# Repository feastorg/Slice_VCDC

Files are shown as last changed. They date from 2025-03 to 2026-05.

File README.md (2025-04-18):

# Current & Voltage Reader Slice

Current and voltage reader slice for AC and DC supplies.

## Introduction

[Short introduction on the project.]

## Usage

[Explain how to use the project. Include examples and screenshots if applicable.]

## Documentation

Please refer to the [docs](/docs) for more info.

---

<div align="center">
  <p>
    
    
  </p>
</div>

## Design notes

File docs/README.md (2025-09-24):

# Notes

## references

-

## parts dump

- PCB TERMINAL BLOCK - LPTA 16/ 2- (1000V, 76A)
  - https://www.digikey.ca/en/products/detail/phoenix-contact/1333817/18175936
- ADUM5010ARSZ isolated dc dc supply
  - https://www.digikey.ca/en/products/detail/analog-devices-inc/ADUM5010ARSZ-RL7/3821210
- 10uF bulk cap: CAP CER 10UF 6.3V X5R 0603
  - https://www.digikey.ca/en/products/detail/tdk-corporation/C1608X5R0J106K080AB/2732927
- 0.1uF HF bypass on iso: CAP CER 0.1UF 50V X5R 0603
  - https://www.digikey.ca/en/products/detail/tdk-corporation/C1608X5R1H104K080AA/2732891
- 10nF EMI filter cap on iso: CAP CER 10000PF 25V C0G 0603
  - https://www.digikey.ca/en/products/detail/kemet/C0603C103J3GECAUTO/6575890
- AMC1311 2-V input, precision voltage sensing reinforced isolated amplifier
  - https://www.digikey.ca/en/products/detail/texas-instruments/AMC1311BDWVR/8020495
  - https://www.ti.com/product/AMC1311
- ACS724LLCTR-50AB-T SENSOR CURRENT HALL IC
  - https://www.digikey.ca/en/products/detail/allegro-microsystems/ACS724LLCTR-50AB-T/5400758
  - https://www.allegromicro.com/en/Products/Sense/Current-Sensor-ICs/Zero-To-Fifty-Amp-Integrated-Conductor-Sensor-ICs/ACS724-5

### other

- ACS37800 - Isolated, Programmable AC and DC Power Monitoring IC with I2C or SPI Interface
  - ACS37800KMACTR-030B3-I2C: https://www.digikey.ca/en/products/detail/allegro-microsystems/ACS37800KMACTR-030B3-I2C/13563666
  - https://www.sparkfun.com/sparkx-power-meter-acs37800-qwiic.html
- Press Fit Terminals
  - [Phoenix Contact TDPT 4/2-SP-635 ZB (Phoenix Contact)](https://www.phoenixcontact.com/en-us/products/printed-circuit-board-terminal-tdpt-4-2-sp-635-zb-1017521)

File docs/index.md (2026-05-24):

---
title: "Slice VCDC Documentation"
description: "Overview and entry page for Slice VCDC project documentation."
nav_exclude: true
---

Welcome to the Slice VCDC project documentation.

## Board Renders

<figure style="display:inline-block; text-align:center; margin:10px;">
  Board Top
  <figcaption>Top</figcaption>
</figure>

<figure style="display:inline-block; text-align:center; margin:10px;">
  Board Bottom
  <figcaption>Bottom</figcaption>
</figure>

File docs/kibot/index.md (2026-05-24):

---
title: "KiBot Outputs"
description: "Index for KiBot-generated PCB artifacts."
layout: "page"
---

These are the docs & KiBot Outputs for Slice VCDC

The following files were generated from the latest PCB build:

- [Schematic.pdf](./Schematic.pdf)
- [PCB.pdf](./PCB.pdf)
- [kibot.log](./kibot.log)
- [BREAD_Slice-bom.html](./BREAD_Slice-bom.html)
- [BREAD_Slice-ibom.html](./BREAD_Slice-ibom.html)

_Last updated automatically by KiBot via GitHub Actions._

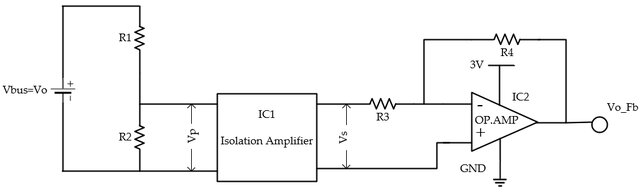
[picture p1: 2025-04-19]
docs/images/Block-diagram-of-the-proposed-isolated-DC-voltage-sensor-VS-2_W640.jpg

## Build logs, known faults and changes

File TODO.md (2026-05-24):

# TODO

## Pass 1 — CI Pipeline

- [x] Pipeline added
- [x] DRC: FAIL
- [x] ERC: PASS
- [ ] Fab: FAIL (Generate SCH files step)
- [ ] gen-kibot-index: SKIPPED
- [ ] deploy-pages: SKIPPED

## Pass 2 — Pre-Fab Review

- [ ] Investigate and fix DRC errors
- [ ] Investigate Fab "Generate SCH files" failure
- [ ] Verify BOM completeness and sourcing
- [ ] Confirm board outline and mounting holes
- [ ] Footprint verification against datasheets
- [ ] Design review sign-off

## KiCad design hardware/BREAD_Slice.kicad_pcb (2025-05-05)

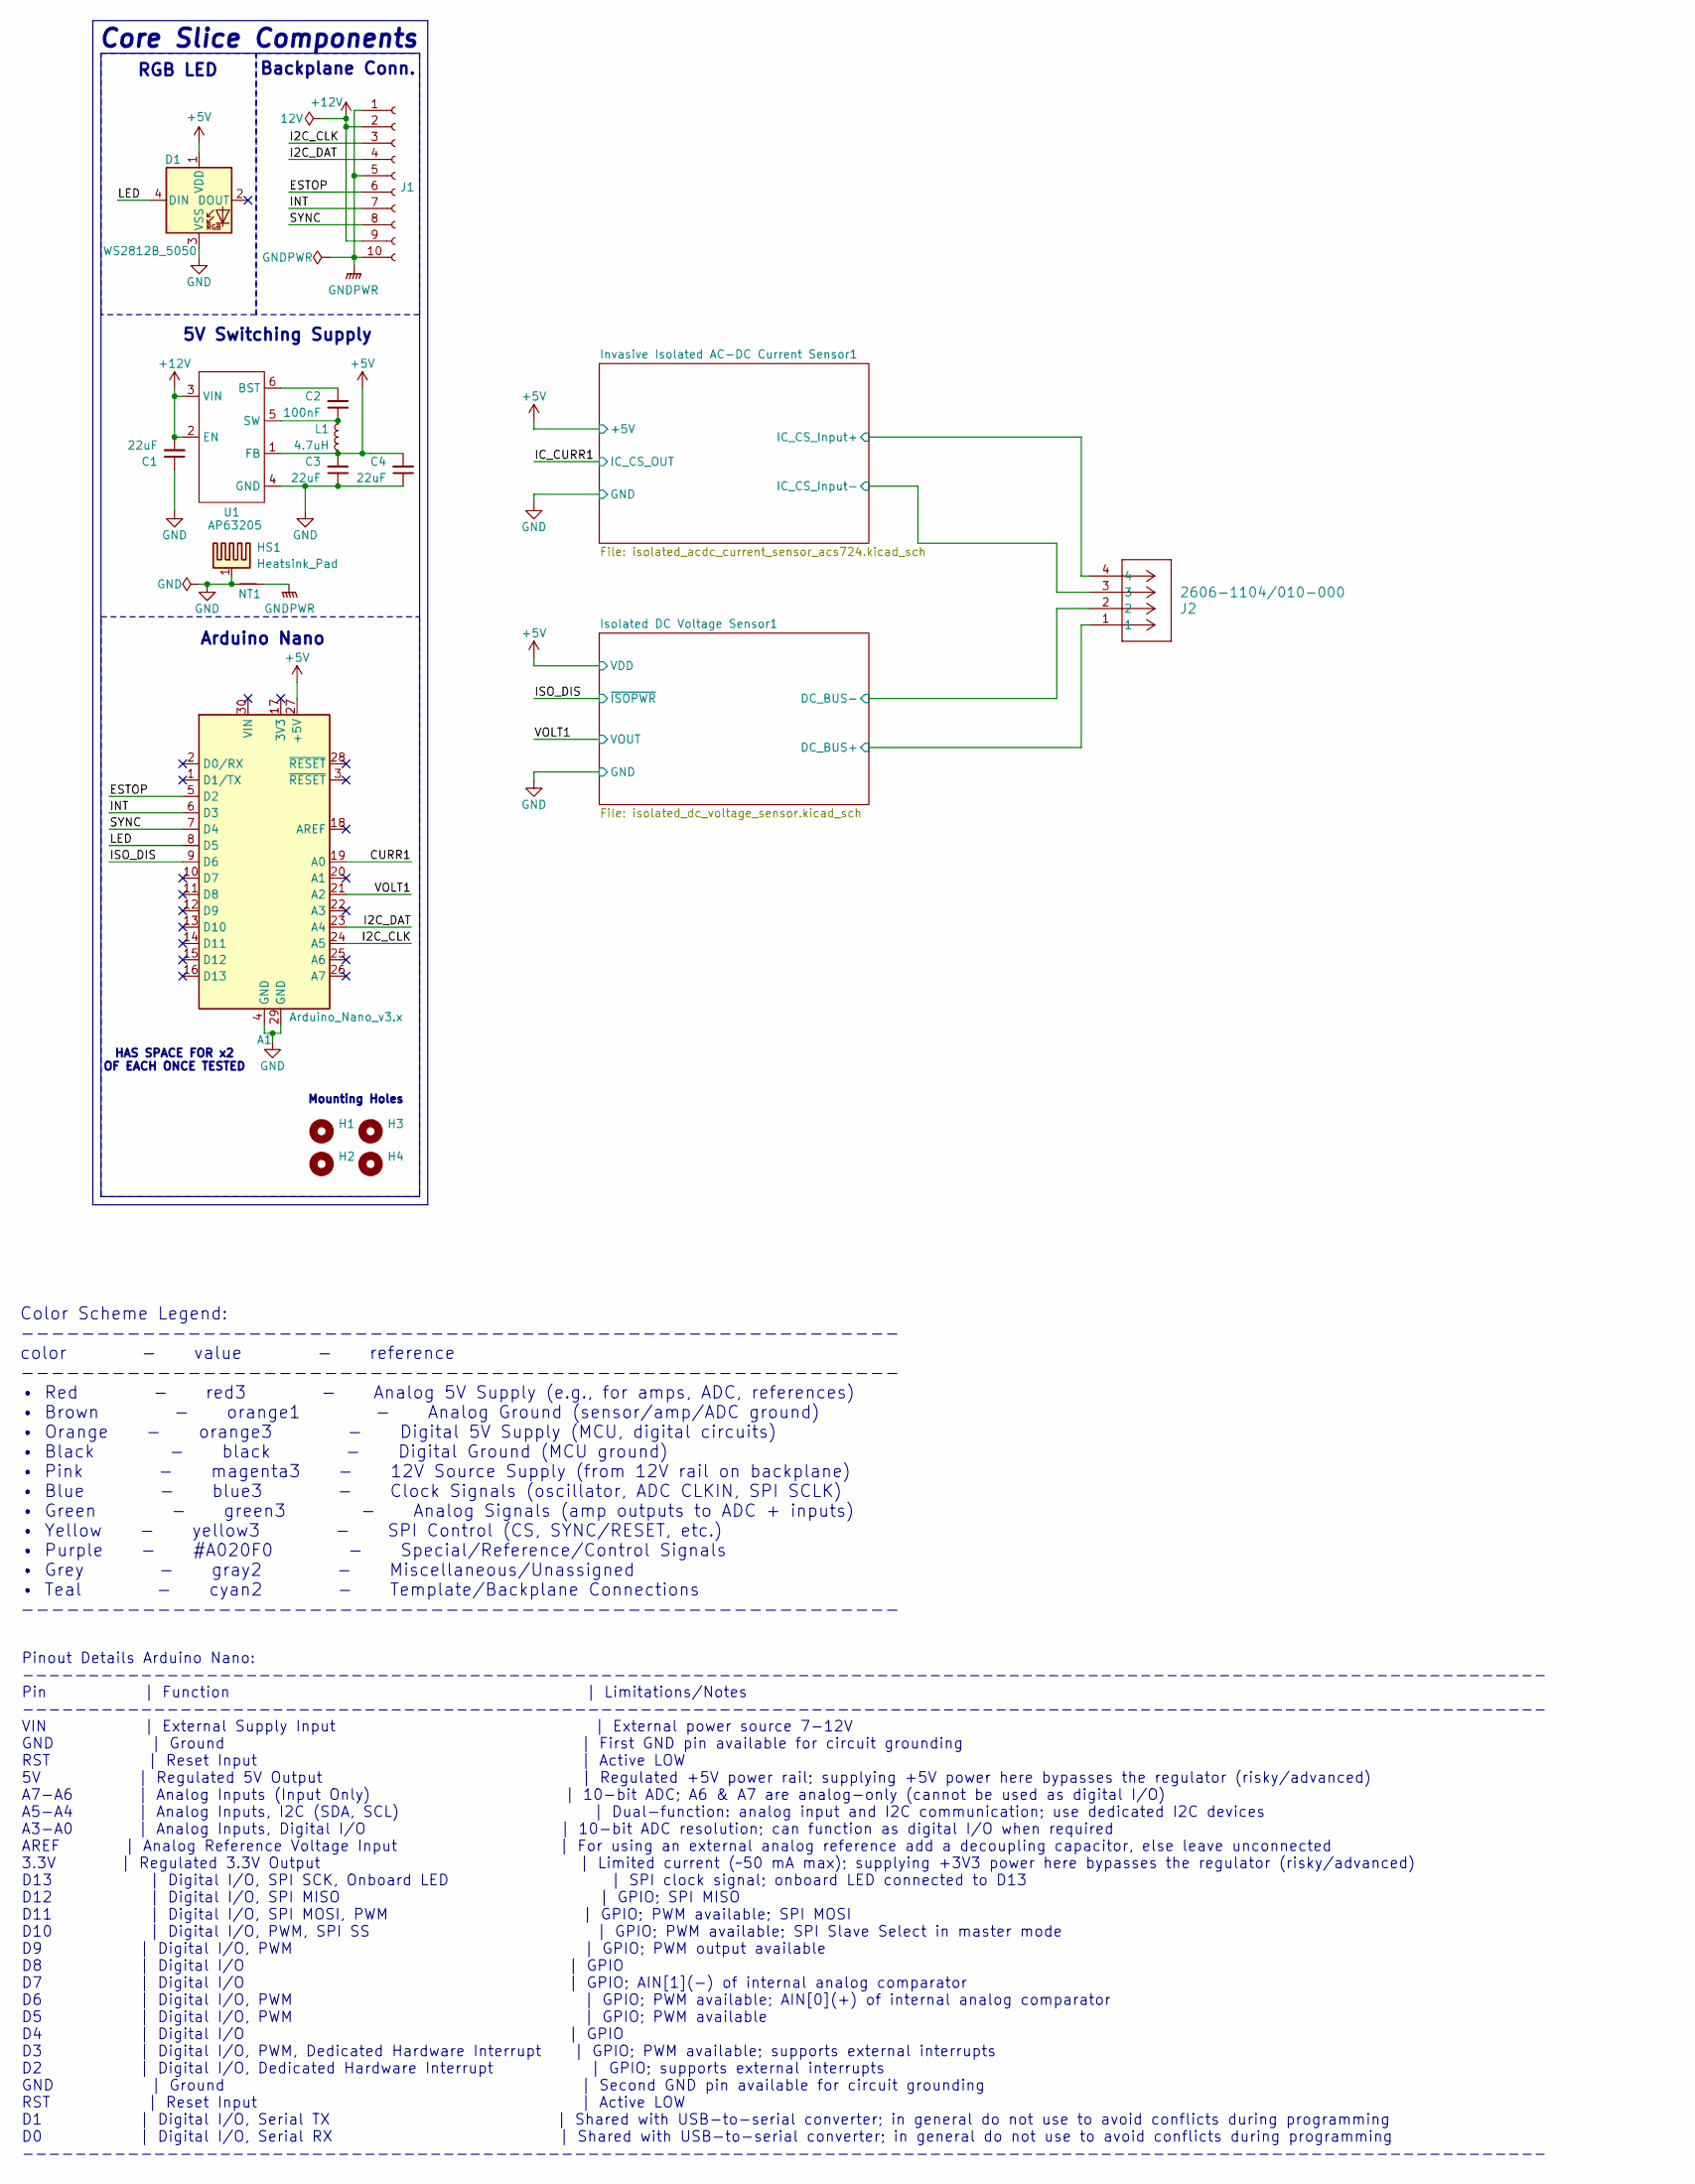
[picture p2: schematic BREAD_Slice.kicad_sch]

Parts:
A1: Arduino_Nano_v3.x; Arduino_Nano
C1, C3, C4: 22uF; C_1206_3216Metric
C2: 100nF; C_1206_3216Metric
D1: WS2812B_5050; WS2812-5050-4PIN
H1, H2, H3, H4: MountingHole; MountingHole_5mm
HS1: Heatsink_Pad; Thermal Pad
J1: Conn_01x10_Female; PinSocket_1x10_P2.54mm_Horizontal
J2: 2606-1104/010-000; CONN4_2606-1104&slash_010-000_WAG
L1: 4.7uH; L_1210_3225Metric
NT1: NetTie_2; NetTie-2_SMD_Pad2.0mm
U1: AP63205; TSOT-23-6

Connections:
+5V: A1.27 (+5V), C3.2, C4.2, D1.1 (VDD), L1.2, U1.1 (FB); also elsewhere on the board
+12V: C1.2, J1.2, J1.9, U1.2 (EN), U1.3 (VIN)
/CURR1: A1.19 (A0)
/ESTOP: A1.5 (D2), J1.6
/I2C_CLK: A1.24 (A5), J1.3
/I2C_DAT: A1.23 (A4), J1.4
/INT: A1.6 (D3), J1.7
/ISO_DIS: A1.9 (D6); also elsewhere on the board
/Invasive Isolated AC-DC Current Sensor1/IC_CS_Input+: J2.4; also elsewhere on the board
/Invasive Isolated AC-DC Current Sensor1/IC_CS_Input-: J2.3; also elsewhere on the board
/Isolated DC Voltage Sensor1/DC_BUS+: J2.1; also elsewhere on the board
/Isolated DC Voltage Sensor1/DC_BUS-: J2.2; also elsewhere on the board
/LED: A1.8 (D5), D1.4 (DIN)
/SYNC: A1.7 (D4), J1.8
/VOLT1: A1.21 (A2); also elsewhere on the board
GND: A1.4 (GND), A1.29 (GND), C1.1, C3.1, C4.1, D1.3 (VSS), HS1.1, NT1.1, U1.4 (GND); also elsewhere on the board
GNDPWR: J1.1, J1.5, J1.10, NT1.2
unnamed: C2.2, U1.6 (BST)
unnamed: C2.1, L1.1, U1.5 (SW)

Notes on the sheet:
5V Switching Supply
HAS SPACE FOR x2 OF EACH ONCE TESTED
Pinout Details Arduino Nano: -------------------------------------------------------------------------------------------------------------------- Pin | Function | Limitations/Notes -------------------------------------------------------------------------------------------------------------------- V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
RGB LED
Color Scheme Legend: ---------------------------------------------------------- color - value - reference ---------------------------------------------------------- • Red - red3 - Analog 5V Supply (e.g., for amps, ADC, references) • Brown - orange1 - Analog Ground (sensor/amp/ADC ground) • Orange -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
Core Slice Components
Arduino Nano
Mounting Holes
Backplane Conn.

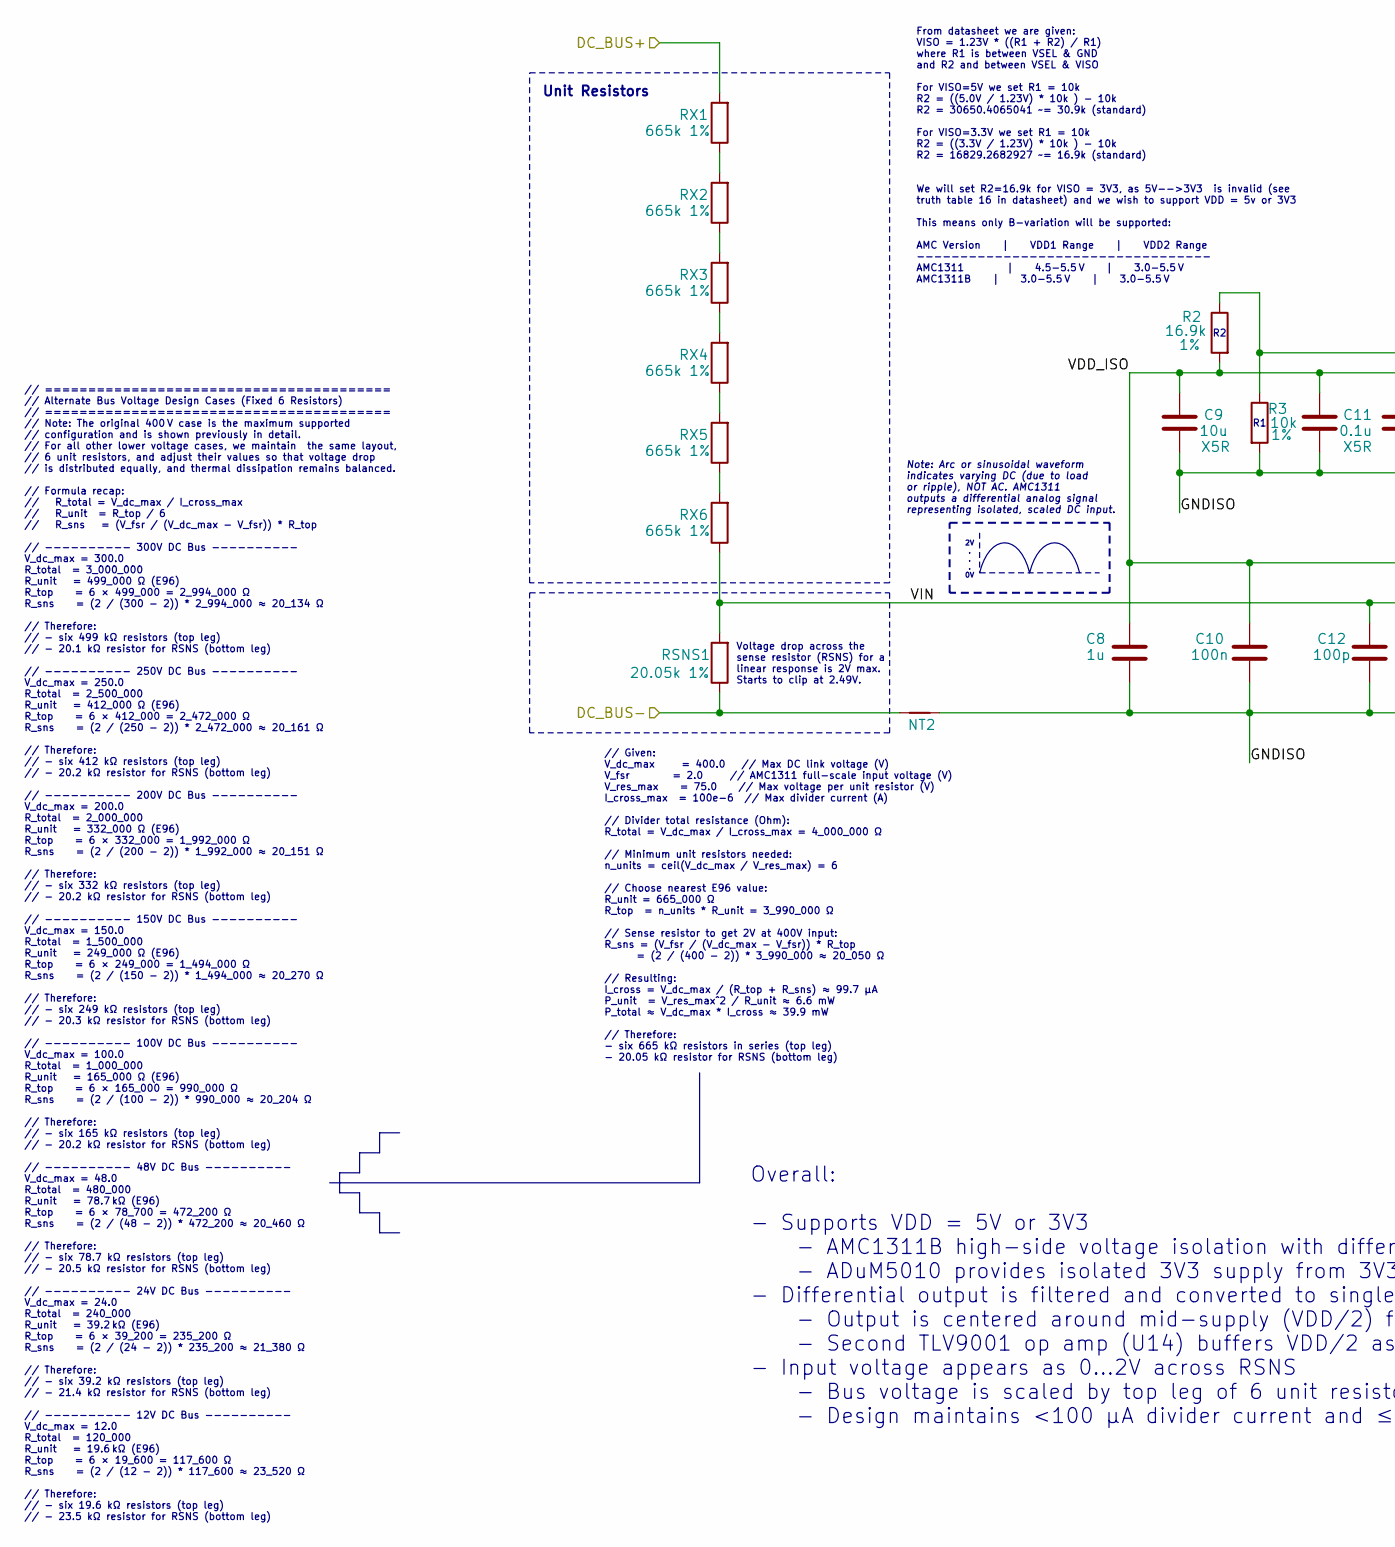
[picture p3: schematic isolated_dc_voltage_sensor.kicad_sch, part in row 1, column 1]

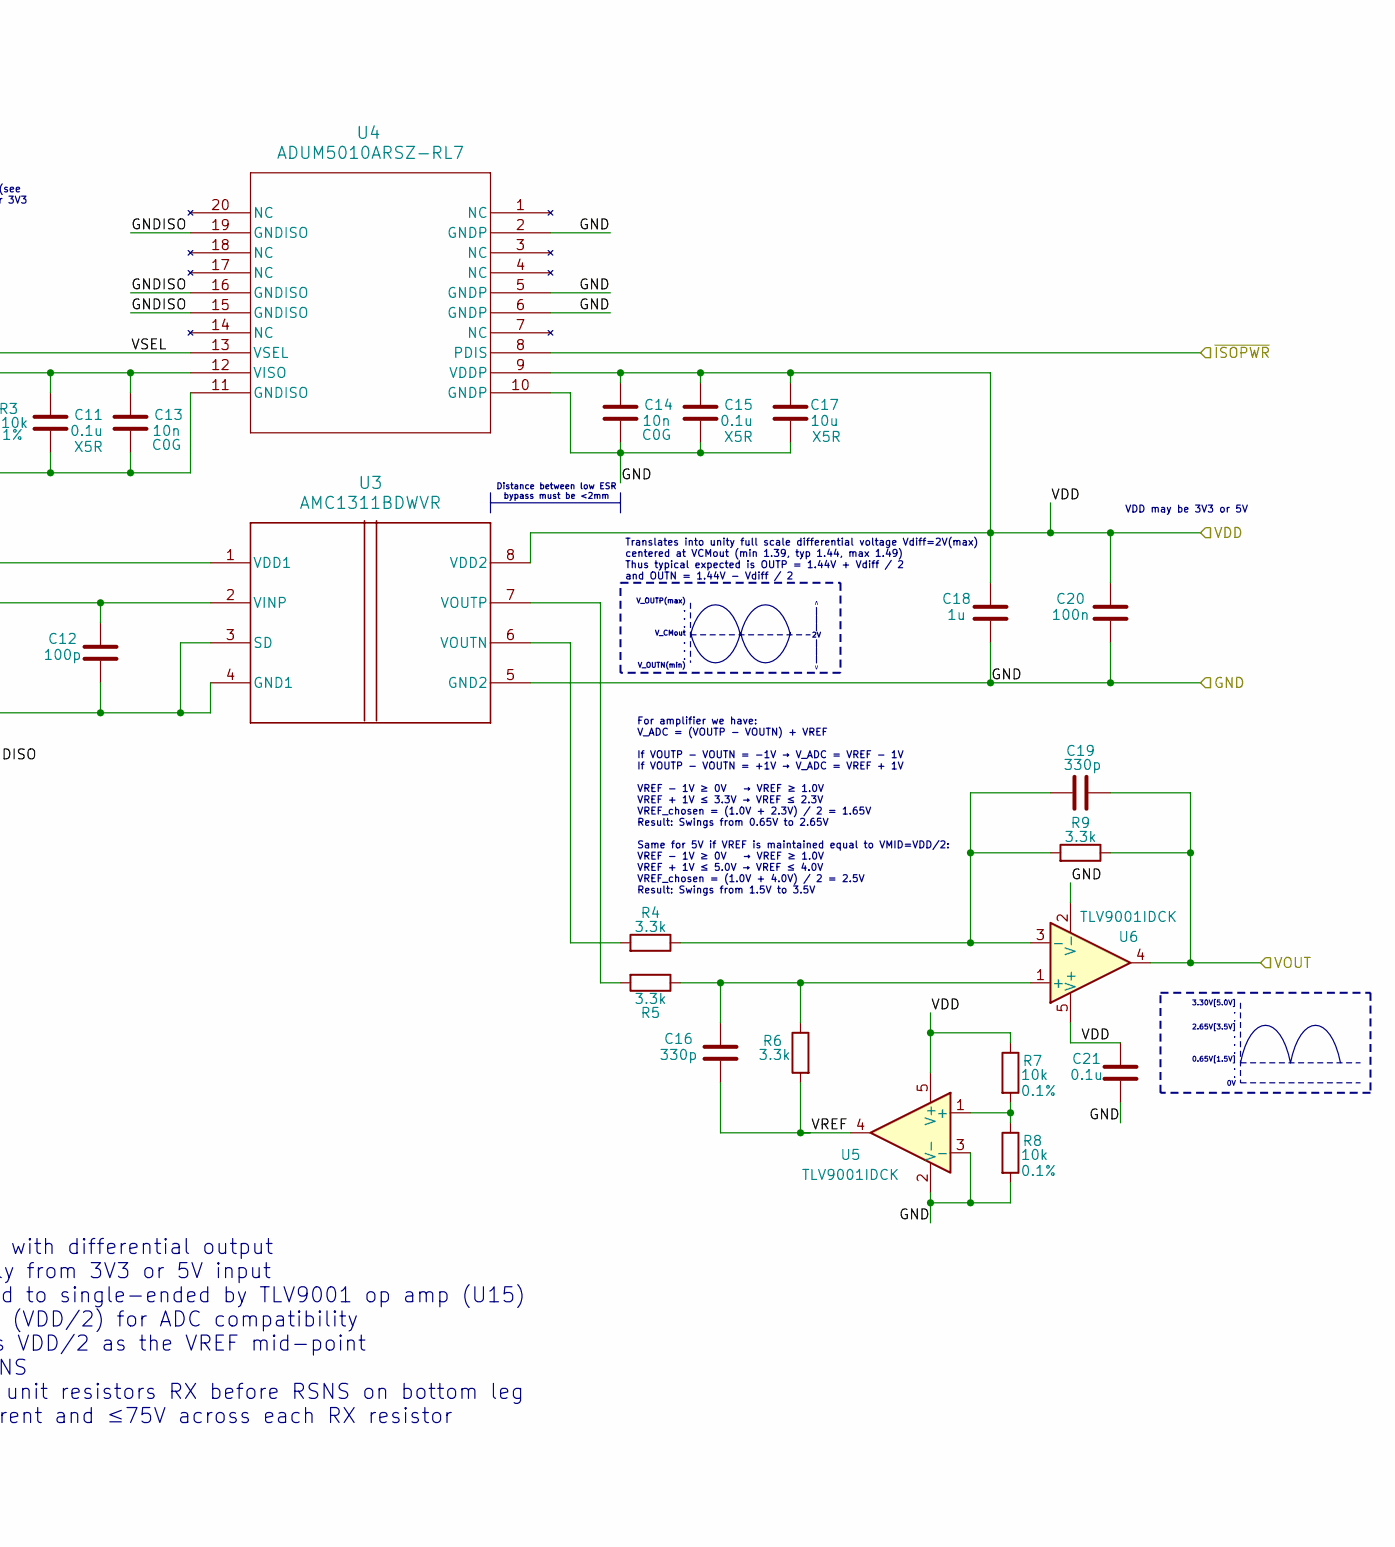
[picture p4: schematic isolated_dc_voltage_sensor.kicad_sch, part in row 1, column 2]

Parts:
C8: 1u; C_0603_1608Metric_Pad1.08x0.95mm_HandSolder
C9, C17: 10u; C_0603_1608Metric_Pad1.08x0.95mm_HandSolder
C10: 100n; C_0603_1608Metric_Pad1.08x0.95mm_HandSolder
C11, C15: 0.1u; C_0603_1608Metric_Pad1.08x0.95mm_HandSolder
C12: 100p; C_0603_1608Metric_Pad1.08x0.95mm_HandSolder
C13, C14: 10n; C_0603_1608Metric_Pad1.08x0.95mm_HandSolder
C16, C19: 330p; C_0805_2012Metric_Pad1.18x1.45mm_HandSolder
C18: 1u; C_0805_2012Metric_Pad1.18x1.45mm_HandSolder
C20: 100n; C_0805_2012Metric_Pad1.18x1.45mm_HandSolder
C21: 0.1u; C_0805_2012Metric_Pad1.18x1.45mm_HandSolder
NT2: NetTie_2; NetTie-2_SMD_Pad0.5mm
R2: 16.9k; R_0603_1608Metric_Pad0.98x0.95mm_HandSolder
R3: 10k; R_0603_1608Metric_Pad0.98x0.95mm_HandSolder
R4, R5, R6, R9: 3.3k; R_0805_2012Metric_Pad1.20x1.40mm_HandSolder
R7, R8: 10k; R_0805_2012Metric_Pad1.20x1.40mm_HandSolder
RSNS1: 20.05k 1%; R_1206_3216Metric_Pad1.30x1.75mm_HandSolder
RX1, RX2, RX3, RX4, RX5, RX6: 665k 1%; R_1206_3216Metric_Pad1.30x1.75mm_HandSolder
U3: AMC1311BDWVR; DWV0008A
U4: ADUM5010ARSZ-RL7; RS_20_ADI
U5, U6: TLV9001IDCK; SOT-353_SC-70-5

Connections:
+5V: C14.2, C15.2, C17.2, C18.2, C20.2, C21.2, R7.1, U3.8 (VDD2), U4.9 (VDDP), U5.5 (V+), U6.5 (V+); also elsewhere on the board
/ISO_DIS: U4.8 (PDIS); also elsewhere on the board
/Isolated DC Voltage Sensor1/DC_BUS+: RX1.2; also elsewhere on the board
/Isolated DC Voltage Sensor1/DC_BUS-: NT2.1, RSNS1.1; also elsewhere on the board
/Isolated DC Voltage Sensor1/GNDISO: C8.1, C9.1, C10.1, C11.1, C12.1, C13.1, NT2.2, R3.2, U3.3 (SD), U3.4 (GND1), U4.11 (GNDISO), U4.15 (GNDISO), U4.16 (GNDISO), U4.19 (GNDISO)
/Isolated DC Voltage Sensor1/VDD_ISO: C8.2, C9.2, C10.2, C11.2, C13.2, R2.2, U3.1 (VDD1), U4.12 (VISO)
/Isolated DC Voltage Sensor1/VIN: C12.2, RSNS1.2, RX6.1, U3.2 (VINP)
/Isolated DC Voltage Sensor1/VREF: C16.1, R6.2, U5.4
/Isolated DC Voltage Sensor1/VSEL: R2.1, R3.1, U4.13 (VSEL)
/VOLT1: C19.2, R9.1, U6.4; also elsewhere on the board
GND: C14.1, C15.1, C17.1, C18.1, C20.1, C21.1, R8.2, U3.5 (GND2), U4.2 (GNDP), U4.5 (GNDP), U4.6 (GNDP), U4.10 (GNDP), U5.2 (V-), U5.3 (-), U6.2 (V-); also elsewhere on the board
unnamed: RX1.1, RX2.2
unnamed: RX2.1, RX3.2
unnamed: RX3.1, RX4.2
unnamed: RX4.1, RX5.2
unnamed: RX5.1, RX6.2
unnamed: R4.2, U3.6 (VOUTN)
unnamed: R5.2, U3.7 (VOUTP)
unnamed: R7.2, R8.1, U5.1 (+)
unnamed: C16.2, R5.1, R6.1, U6.1 (+)
unnamed: C19.1, R4.1, R9.2, U6.3 (-)

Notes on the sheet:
VDD may be 3V3 or 5V
// Given: V_dc_max = 400.0 // Max DC link voltage (V) V_fsr = 2.0 // AMC1311 full-scale input voltage (V) V_res_max = 75.0 // Max voltage per unit resistor (V) I_cross_max = 100e-6 // Max divider current (A) // Divider total resistance (Ohm): R_total = V_dc_max / I_cross_max = 4_000_000 Ω // Minimu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
// ======================================== // Alternate Bus Voltage Design Cases (Fixed 6 Resistors) // ======================================== // Note: The original 400 V case is the maximum supported // configuration and is shown previously in detail. // For all other lower voltage cases, we ma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
∧ | | | 2V | | | ∨
Voltage drop across the sense resistor (RSNS) for a linear response is 2V max. Starts to clip at 2.49V.
Overall: - Supports VDD = 5V or 3V3 - AMC1311B high-side voltage isolation with differential output - ADuM5010 provides isolated 3V3 supply from 3V3 or 5V input - Differential output is filtered and converted to single-ended by TLV9001 op amp (U15) - Output is centered around mid-supply (VDD/2) for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
2V . . . 0V
3.30V[5.0V] . . 2.65V[3.5V] . . . 0.65V[1.5V] . . 0V
Unit Resistors
Distance between low ESR bypass must be <2mm
For amplifier we have: V_ADC = (VOUTP - VOUTN) + VREF If VOUTP - VOUTN = -1V → V_ADC = VREF - 1V If VOUTP - VOUTN = +1V → V_ADC = VREF + 1V VREF - 1V ≥ 0V → VREF ≥ 1.0V VREF + 1V ≤ 3.3V → VREF ≤ 2.3V VREF_chosen = (1.0V + 2.3V) / 2 = 1.65V Result: Swings from 0.65V to 2.65V Same for 5V if VREF is m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
From datasheet we are given: VISO = 1.23V * ((R1 + R2) / R1) where R1 is between VSEL & GND and R2 and between VSEL & VISO For VISO=5V we set R1 = 10k R2 = ((5.0V / 1.23V) * 10k ) - 10k R2 = 30650.4065041 ~= 30.9k (standard) For VISO=3.3V we set R1 = 10k R2 = ((3.3V / 1.23V) * 10k ) - 10k R2 = 1682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
Translates into unity full scale differential voltage Vdiff=2V(max) centered at VCMout (min 1.39, typ 1.44, max 1.49) Thus typical expected is OUTP = 1.44V + Vdiff / 2 and OUTN = 1.44V - Vdiff / 2
V_OUTP(max) . . . V_CMout . . . V_OUTN(min)
Note: Arc or sinusoidal waveform indicates varying DC (due to load or ripple), NOT AC. AMC1311 outputs a differential analog signal representing isolated, scaled DC input.

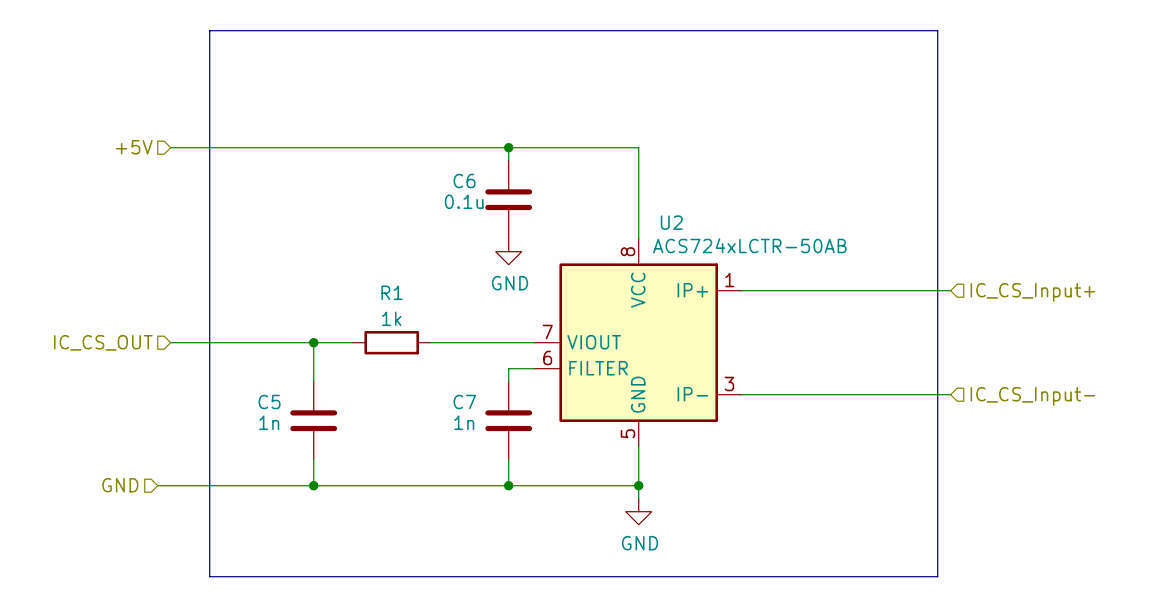
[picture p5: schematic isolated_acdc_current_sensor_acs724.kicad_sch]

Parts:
C5, C7: 1n; C_0805_2012Metric_Pad1.18x1.45mm_HandSolder
C6: 0.1u; C_0805_2012Metric_Pad1.18x1.45mm_HandSolder
R1: 1k; R_0805_2012Metric_Pad1.20x1.40mm_HandSolder
U2: ACS724xLCTR-50AB; SOIC-8_3.9x4.9mm_P1.27mm

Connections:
+5V: C6.2, U2.8 (VCC); also elsewhere on the board
/IC_CURR1: C5.2, R1.1
/Invasive Isolated AC-DC Current Sensor1/IC_CS_Input+: U2.1 (IP+), U2.2 (IP+); also elsewhere on the board
/Invasive Isolated AC-DC Current Sensor1/IC_CS_Input-: U2.3 (IP-), U2.4 (IP-); also elsewhere on the board
GND: C5.1, C6.1, C7.1, U2.5 (GND); also elsewhere on the board
unnamed: C7.2, U2.6 (FILTER)
unnamed: R1.2, U2.7 (VIOUT)

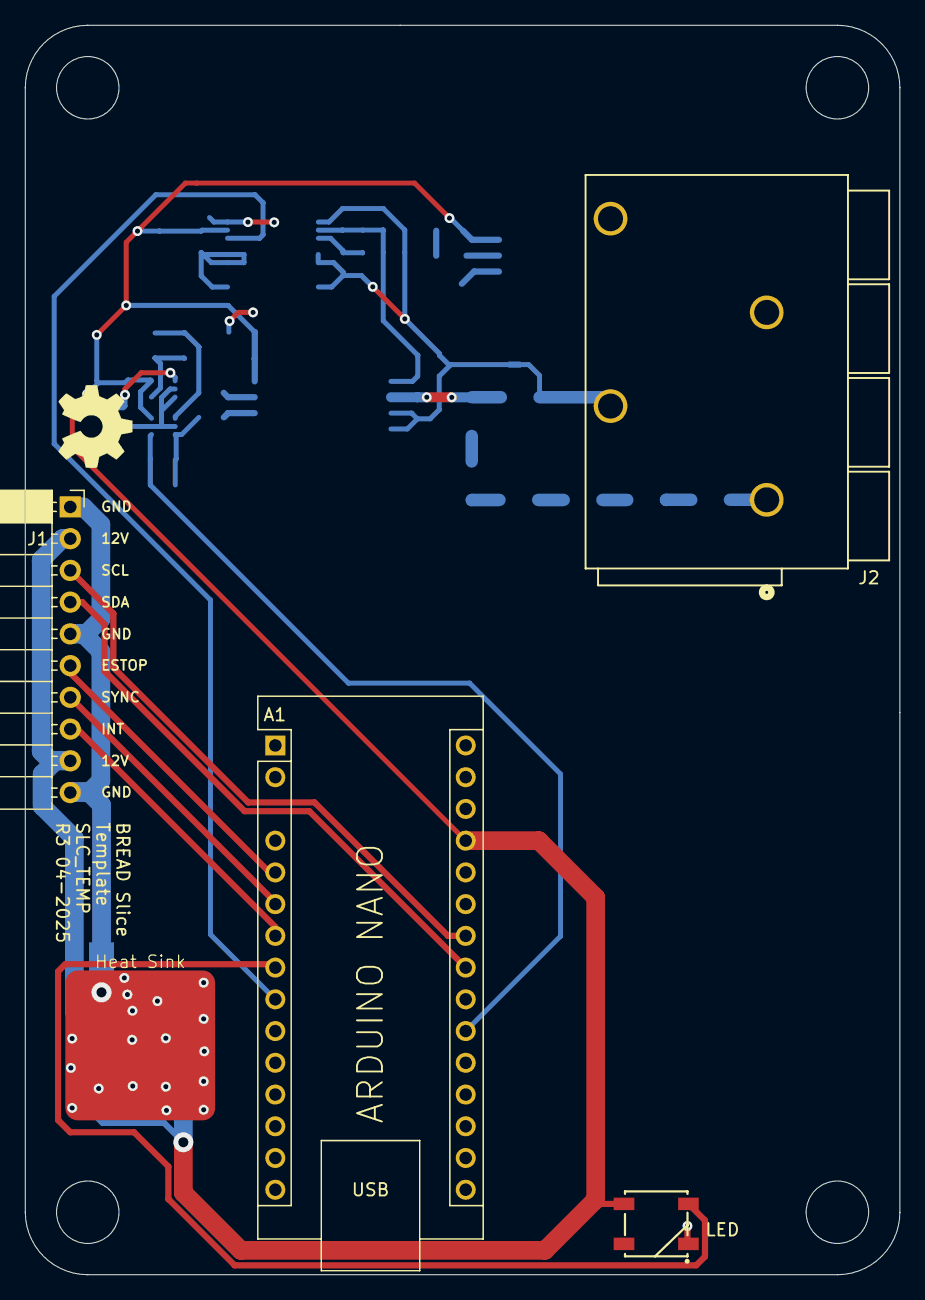
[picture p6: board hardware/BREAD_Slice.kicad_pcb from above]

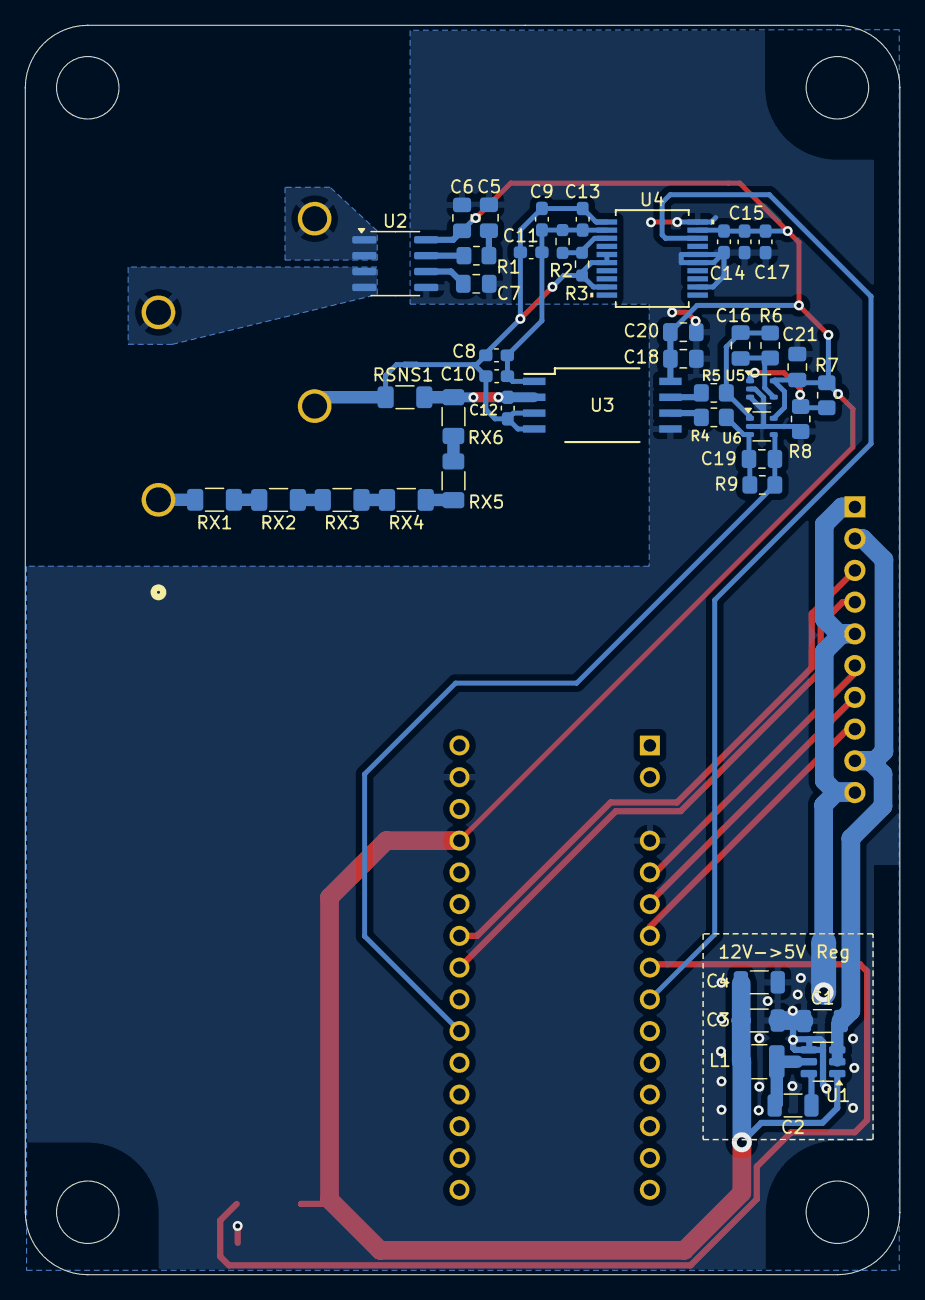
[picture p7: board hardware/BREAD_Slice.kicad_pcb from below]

Board: 2 copper layers, 70.0 x 100.0 mm, 56 parts (46 on the bottom side), 36 nets.

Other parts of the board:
Logo1: Logo_Open_Hardware_Small; OSHW-Symbol_6.7x6mm_SilkScreen

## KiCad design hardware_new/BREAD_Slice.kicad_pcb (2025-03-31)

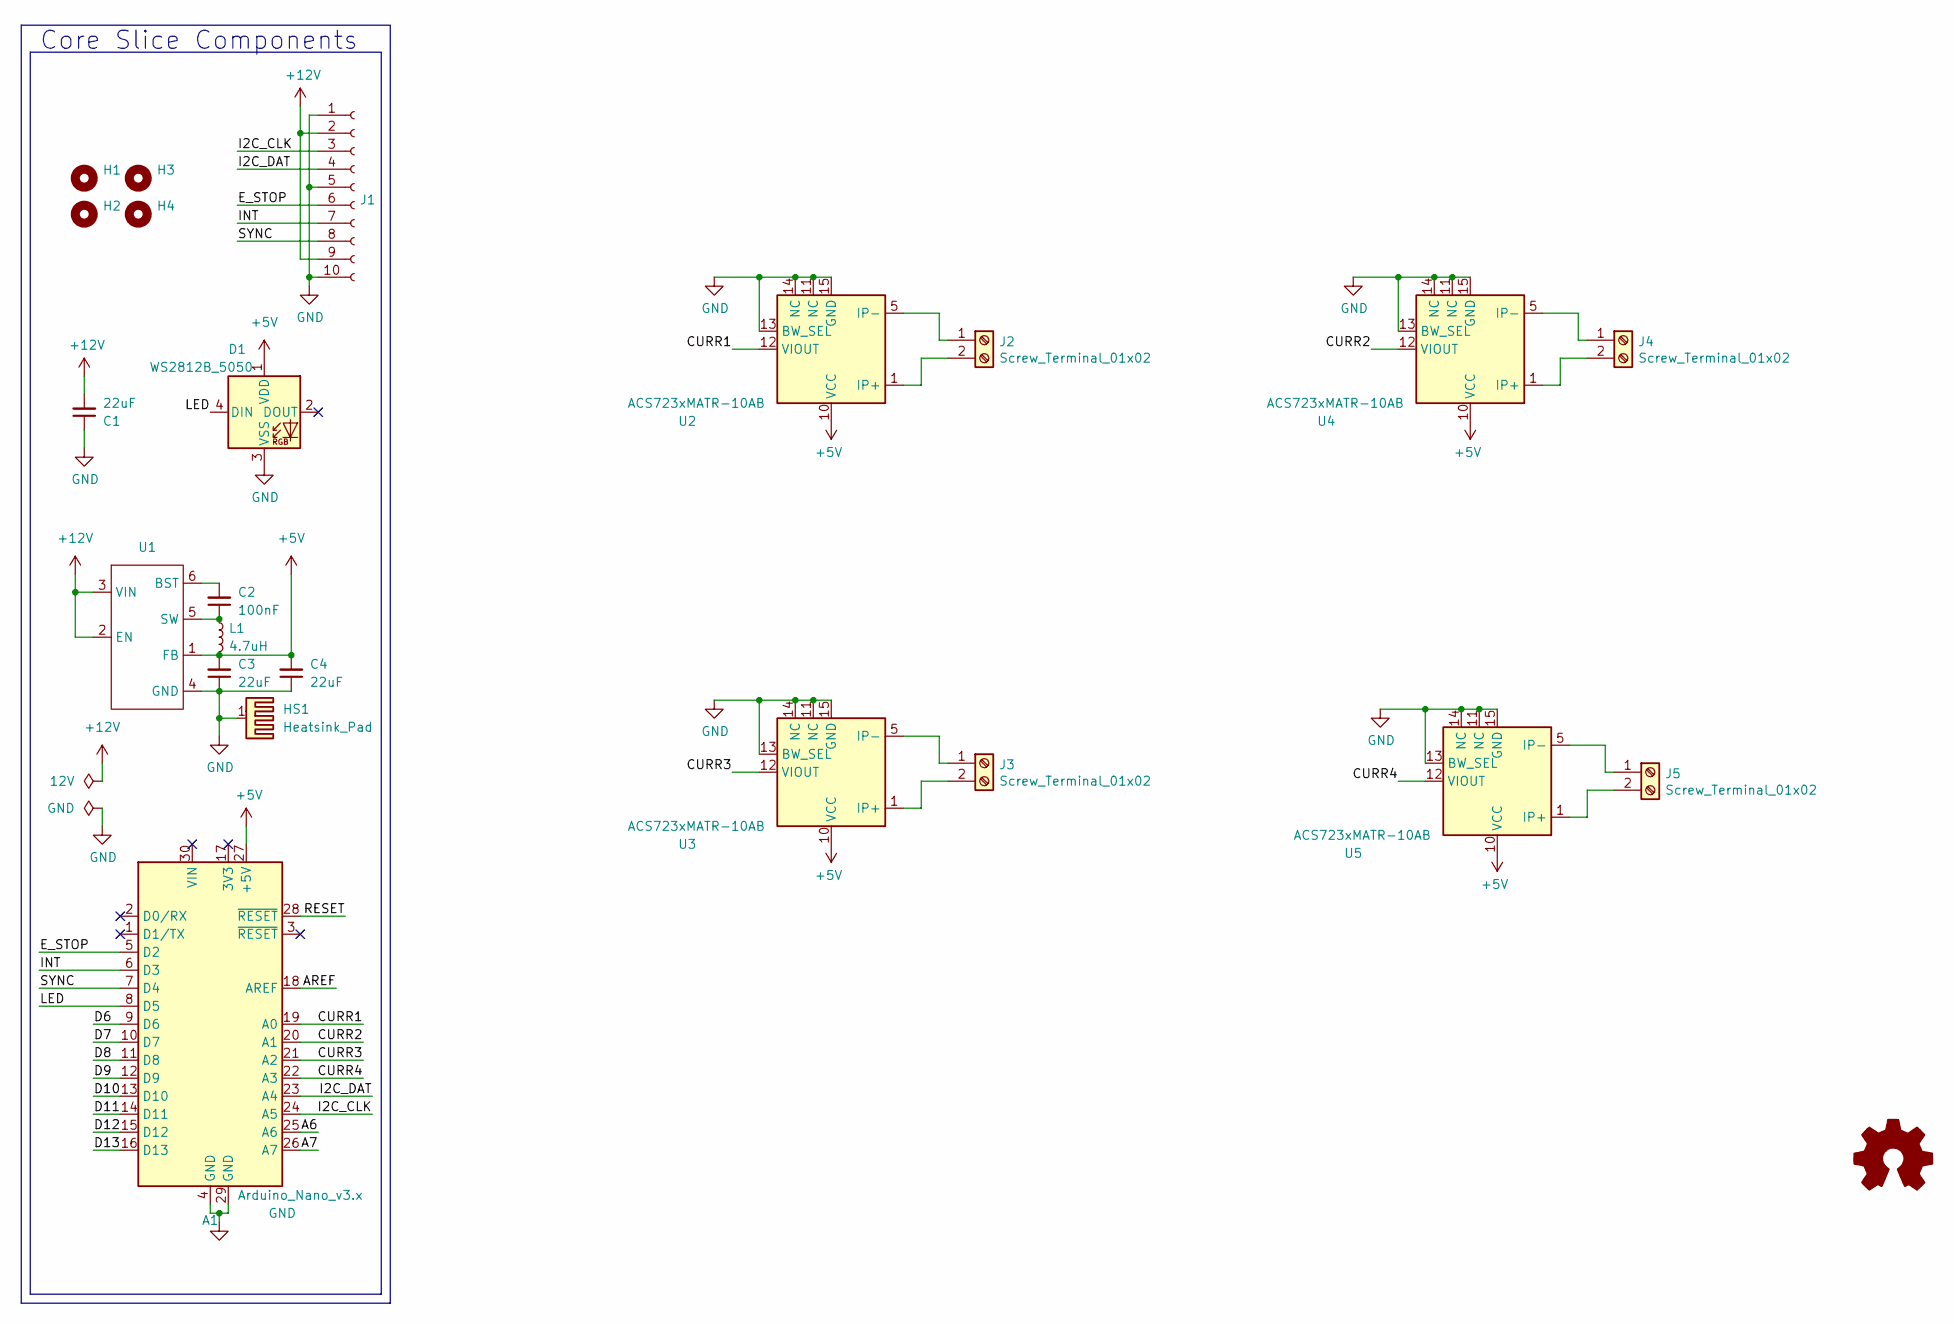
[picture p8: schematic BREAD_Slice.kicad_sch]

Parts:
A1: Arduino_Nano_v3.x; Arduino_Nano
C1, C3, C4: 22uF; C_1206_3216Metric
C2: 100nF; C_1206_3216Metric
D1: WS2812B_5050; WS2812-5050-4PIN
H1, H2, H3, H4: MountingHole; MountingHole_5mm
HS1: Heatsink_Pad; Thermal Pad
J1: Conn_01x10_Female; PinSocket_1x10_P2.54mm_Horizontal
J2, J3, J4, J5: Screw_Terminal_01x02; Pheonix Conn Term TDPT 4 2-SP-6,35-ZB
L1: 4.7uH; L_1210_3225Metric
U1: TSOT-23-6
U2, U3, U4, U5: ACS723xMATR-10AB; SOIC-16W_7.5x10.3mm_P1.27mm

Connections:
+5V: A1.27 (+5V), C3.2, C4.2, D1.1 (VDD), L1.2, U1.1 (FB), U2.10 (VCC), U3.10 (VCC), U4.10 (VCC), U5.10 (VCC)
+12V: C1.2, J1.2, J1.9, U1.2 (EN), U1.3 (VIN)
/A6: A1.25 (A6)
/A7: A1.26 (A7)
/AREF: A1.18 (AREF)
/CURR1: A1.19 (A0), U2.12 (VIOUT)
/CURR2: A1.20 (A1), U4.12 (VIOUT)
/CURR3: A1.21 (A2), U3.12 (VIOUT)
/CURR4: A1.22 (A3), U5.12 (VIOUT)
/D6: A1.9 (D6)
/D7: A1.10 (D7)
/D8: A1.11 (D8)
/D9: A1.12 (D9)
/D10: A1.13 (D10)
/D11: A1.14 (D11)
/D12: A1.15 (D12)
/D13: A1.16 (D13)
/E_STOP: A1.5 (D2), J1.6
/I2C_CLK: A1.24 (A5), J1.3
/I2C_DAT: A1.23 (A4), J1.4
/INT: A1.6 (D3), J1.7
/LED: A1.8 (D5), D1.4 (DIN)
/RESET: A1.28 (~RESET)
/SYNC: A1.7 (D4), J1.8
GND: A1.4 (GND), A1.29 (GND), C1.1, C3.1, C4.1, D1.3 (VSS), HS1.1, J1.1, J1.5, J1.10, U1.4 (GND), U2.11 (NC), U2.13 (BW_SEL), U2.14 (NC), U2.15 (GND), U3.11 (NC), U3.13 (BW_SEL), U3.14 (NC), U3.15 (GND), U4.11 (NC), U4.13 (BW_SEL), U4.14 (NC), U4.15 (GND), U5.11 (NC), U5.13 (BW_SEL), U5.14 (NC), U5.15 (GND)
unnamed: J2.1, U2.5 (IP-), U2.6 (IP-), U2.7 (IP-), U2.8 (IP-)
unnamed: J2.2, U2.1 (IP+), U2.2 (IP+), U2.3 (IP+), U2.4 (IP+)
unnamed: J3.1, U3.5 (IP-), U3.6 (IP-), U3.7 (IP-), U3.8 (IP-)
unnamed: J3.2, U3.1 (IP+), U3.2 (IP+), U3.3 (IP+), U3.4 (IP+)
unnamed: J4.1, U4.5 (IP-), U4.6 (IP-), U4.7 (IP-), U4.8 (IP-)
unnamed: J4.2, U4.1 (IP+), U4.2 (IP+), U4.3 (IP+), U4.4 (IP+)
unnamed: J5.1, U5.5 (IP-), U5.6 (IP-), U5.7 (IP-), U5.8 (IP-)
unnamed: J5.2, U5.1 (IP+), U5.2 (IP+), U5.3 (IP+), U5.4 (IP+)
unnamed: C2.2, U1.6 (BST)
unnamed: C2.1, L1.1, U1.5 (SW)

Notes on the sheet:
Core Slice Components

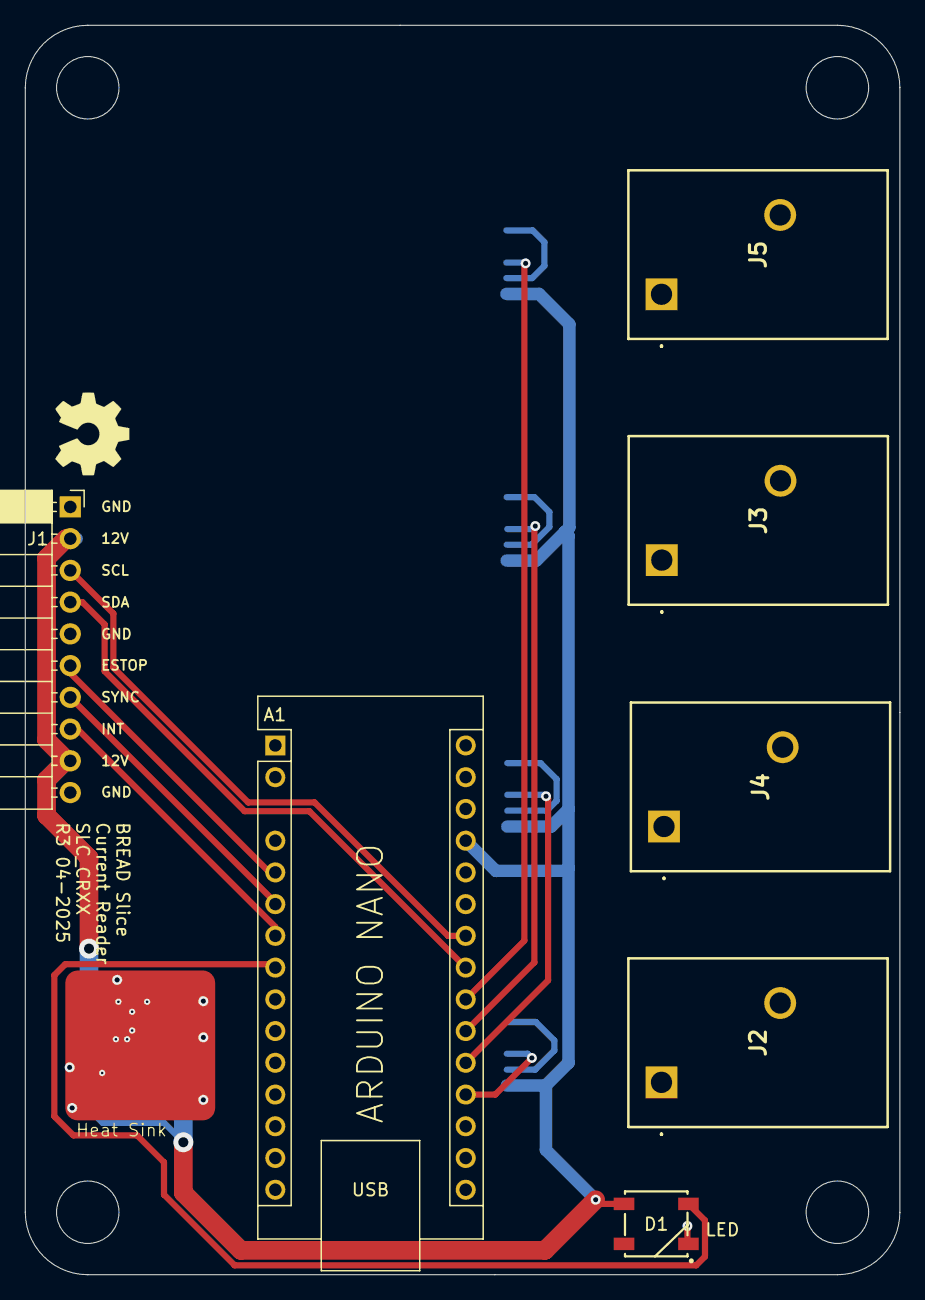
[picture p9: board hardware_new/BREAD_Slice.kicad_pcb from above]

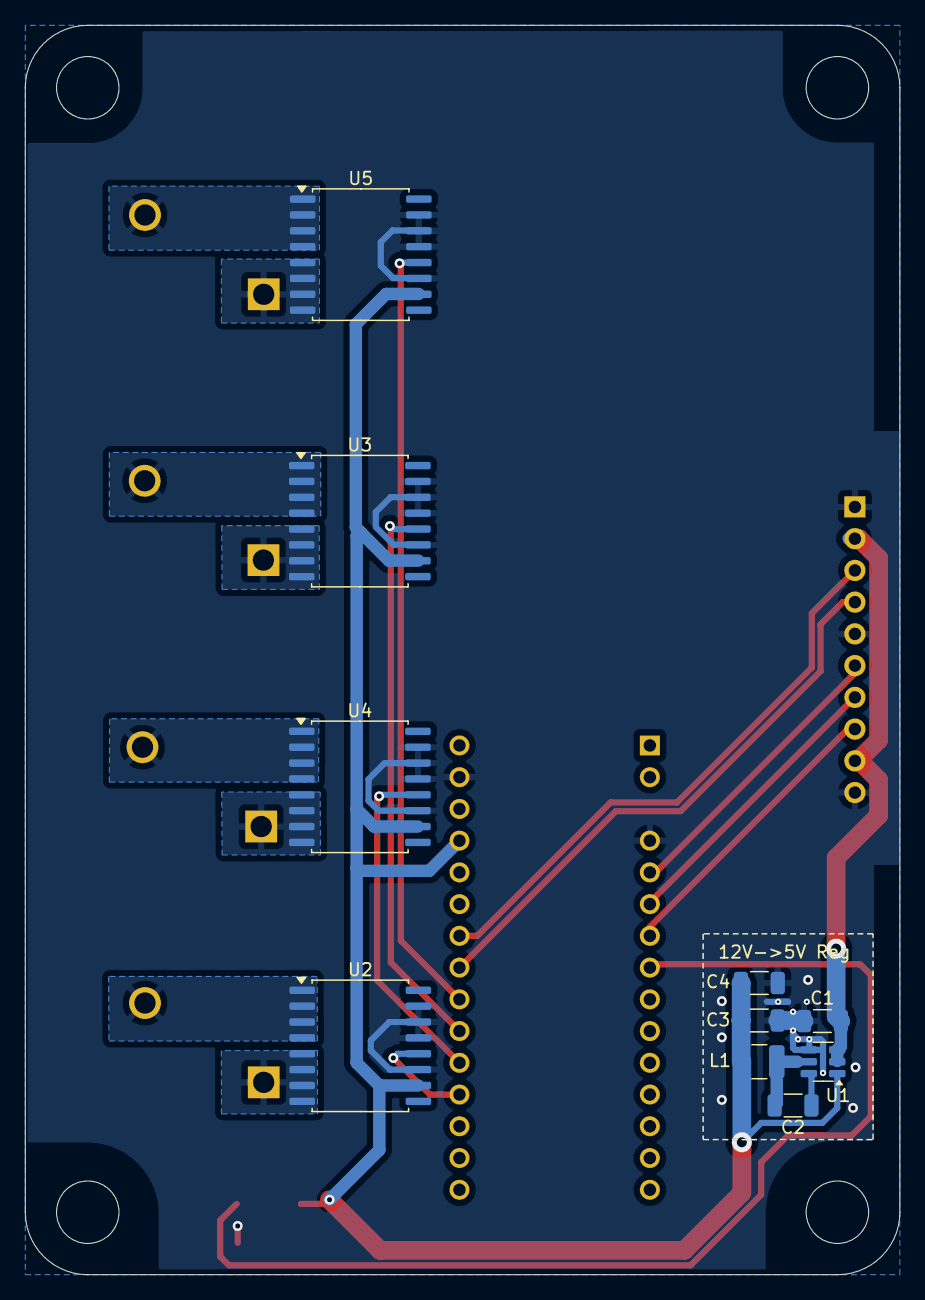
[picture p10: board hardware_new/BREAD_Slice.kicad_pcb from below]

Board: 2 copper layers, 70.0 x 100.0 mm, 23 parts (10 on the bottom side), 23 nets.

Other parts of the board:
Logo1: Logo_Open_Hardware_Small; OSHW-Symbol_6.7x6mm_SilkScreen

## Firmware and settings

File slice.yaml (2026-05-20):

schema_version: "1.0"

# ── Identity ──────────────────────────────────────────────────────────────────
id: "slice-vcdc"
name: "DC Voltage and Current Sensor"
status: "prototype"
category: "sensing"

summary: "Isolated DC voltage (AMC1311) and current (ACS724) measurement slice."
description: null

# ── Versioning ────────────────────────────────────────────────────────────────
version:
  hardware: "0.1.0"
  firmware: "0.1.0"
  manifest: "0.1.0"

# ── Compatibility ─────────────────────────────────────────────────────────────
compatibility:
  slice_spec: ">=0.1.0 <0.2.0"
  crumbs_protocol: null
  anolis_provider_api: null

# ── Hardware ──────────────────────────────────────────────────────────────────
hardware:
  mcu:
    type: "dev-board-socket"
    form_factor: "nano"
    primary: "ATmega328P"
    supported:
      - "ATmega328P"
  primary_ic:
    manufacturer: "Allegro MicroSystems"
    part_number: "ACS724"
  hw_gen_current: 1
  hw_gen_supported: [1]
  pcb:
    layers: 2
    thickness: "1.6mm"
    copper_weight: "1oz"
    dimensions: "70mm x 100mm"
  connectors:
    - ref: "J1"
      type: "slice-bus-10pin"
      purpose: "power-and-i2c"
  mounting:
    pattern: "slice-standard-v0"
    hole_size: "M3"
    inset: "5mm"
  pcb_color_prototype: null
  pcb_color_production: null
  enclosure:
    supported: false
    path: null

# ── Electrical ────────────────────────────────────────────────────────────────
electrical:
  input_voltage: "12V"
  logic_voltage: "5V"
  max_current: null
  protection: null
  isolation:
    present: true

# ── Interfaces ────────────────────────────────────────────────────────────────
interfaces:
  host:
    type: "i2c"
    address_default: 18
    address_configurable: false
  data:
    inputs:
      - name: "DC_CURRENT_1"
        type: "hall-effect-current"
      - name: "DC_CURRENT_2"
        type: "hall-effect-current"
      - name: "DC_CURRENT_3"
        type: "hall-effect-current"
      - name: "DC_CURRENT_4"
        type: "hall-effect-current"
    outputs: []

# ── Capabilities ──────────────────────────────────────────────────────────────
capabilities:
  - id: "dc_current_measurement"
    channels: 4
    control_modes: []
  - id: "dc_voltage_measurement"
    channels: 1
    control_modes: []

# ── Firmware ──────────────────────────────────────────────────────────────────
firmware:
  language: "C++"
  framework: "arduino"
  build_system: "arduino-ide"
  entry_point: "firmware/CR10.ino"
  path: "firmware"
  required: false
  targets:
    - "nano"
  lib_deps:
    - "Wire"
    - "SPI"
  i2c:
    address_default: 18
    address_configurable: false
  libraries:
    - name: "Wire"
      purpose: "I2C communication"
    - name: "SPI"
      purpose: "SPI bus"

# ── Protocol ──────────────────────────────────────────────────────────────────
protocol:
  type: "i2c-register"
  description: "I2C slave at address 18; returns 4-channel current readings as float unions on request."
  commands: []

# ── Software ──────────────────────────────────────────────────────────────────
software: null

# ── Artifacts ─────────────────────────────────────────────────────────────────
artifacts:
  schematic: "hardware/BREAD_Slice.kicad_sch"
  pcb: "hardware/BREAD_Slice.kicad_pcb"
  firmware: "firmware/CR10.ino"
  docs: "docs/"
  bom: "docs/BOM_TEMP.ods"
  gerbers: null
  pick_and_place: null
  datasheets:
    - "docs/ACS724-Datasheet.pdf"
    - "docs/ADuM5010.pdf"
    - "docs/amc1311.pdf"

# ── Manufacturing ─────────────────────────────────────────────────────────────
manufacturing: null

# ── Validation ────────────────────────────────────────────────────────────────
validation: null

# ── Safety ────────────────────────────────────────────────────────────────────
safety:
  hazards:
    - "High DC voltage/current on input side"
  max_safe_voltage: "48VDC"
  intended_environment: "lab"
  not_for:
    - "human safety critical systems"

# ── Dependencies ──────────────────────────────────────────────────────────────
dependencies: null

# ── Relations ─────────────────────────────────────────────────────────────────
related:
  supersedes: null
  superseded_by: null
  variants: []
  compatible_slices:
    - "slice-vcac"

# ── Maintainers ───────────────────────────────────────────────────────────────
maintainers:
  - name: "Cameron Brooks"
    role: "owner"

# ── License ───────────────────────────────────────────────────────────────────
license:
  hardware: "CERN-OHL-S-2.0"
  firmware: "GPL-3.0-only"
  software: null
  docs: "CC-BY-4.0"

# ── Repository ────────────────────────────────────────────────────────────────
repository:
  url: "https://github.com/feastorg/Slice_VCDC"

# ── Metadata ──────────────────────────────────────────────────────────────────
metadata:
  created: "2026-05-19"
  updated: "2026-05-19"
  tags:
    - "power-monitoring"
    - "dc-voltage"
    - "dc-current"
    - "hall-effect"
    - "isolation"

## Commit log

2024-08-30 updated fabrication outputs
    [BREAD_Slice-B_Cu.gbr, BREAD_Slice-B_Mask.gbr, BREAD_Slice-B_Paste.gbr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]
2024-09-27 updated silkscreen info
    [BREAD_Slice-B_Cu.gbr, BREAD_Slice-B_Mask.gbr, BREAD_Slice-B_Paste.gbr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]
2025-03-31 updated to latest template
    [BREAD_Slice-B_Cu.gbr, BREAD_Slice-B_Mask.gbr, BREAD_Slice-B_Paste.gbr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]
2025-03-31 removed old
    [BREAD_Slice-B_Cu.gbr, BREAD_Slice-B_Mask.gbr, BREAD_Slice-B_Paste.gbr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]
2025-04-05 added updated CRXX and schem for CRVS iteration
    [BREAD_Slice.kicad_pcb, BREAD_Slice.kicad_sch, isolated_voltage_sensor.kicad_sch]
2025-04-18 updated board, last push before change to CRVR
    [isolated_voltage_sensor.kicad_sch]
2025-04-19 final schematic done before split to ac dc
    [BOM_CR10.csv, BOM_CR10.ods, BREAD_Slice.kicad_sch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]
2025-04-19 initial commit after split of ac and dc
    [BREAD_Slice.kicad_pcb, BREAD_Slice.kicad_sch, isolated_ac_voltage_sensor.kicad_sch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]
2025-04-19 minor tweaks
    [BREAD_Slice.kicad_pcb]
2025-05-05 completed board
    [BOM_TEMP.ods, BREAD_Slice.kicad_pcb, BREAD_Slice.kicad_sch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]
